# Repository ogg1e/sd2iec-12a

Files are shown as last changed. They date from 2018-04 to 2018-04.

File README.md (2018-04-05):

# sd2iec-1.2a
SD2IEC v1.2a Schematics in Eagle Format

I modified the design to remove all the extra headers and add next/prev/reset buttons based on tactile switches from e-switch (4.5x4.5mm smd).
It also uses a connector from amp to connect to the serial port and cassette port for power. It's optional of course and you can just wire it directly to the board.

The sd card slot I used was like this one (26x26x2.5mm):

https://www.ebay.ca/sch/i.html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

I also added a BOM that can be used at digikey. All parts where in stock when I created the BOM.

Based on the work from here: https://www.c64-wiki.com/wiki/SD2IEC

direct Link: https://www.c64-wiki.com/images/0/0d/sd2iec_12a_full.zip

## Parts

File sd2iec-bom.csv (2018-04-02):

Manufacturer Part Number | Manufacturer | Digi-Key Part Number | Customer Reference | Reference Designator | Packaging | Part Status | Quantity | Unit Price | Extended Price | Quantity Available | Mfg Std Lead Time | Description | RoHS Status | Lead Free Status | REACH Status
CL31C560JBCNNNC | Samsung Electro-Mechanics | 1276-1266-1-ND | sd2iec-c4,c5 | c4,c5 | Cut Tape (CT) | Active | 2 | 0.24000 | $0.48 | 0 | 38 Weeks | CAP CER 56PF 50V C0G/NP0 1206 | RoHS Compliant | Lead free | REACH Unaffected
ATMEGA1284P-AU | Microchip Technology | ATMEGA1284P-AU-ND | sd2iec - ic1 | ic1 | Tray | Active | 1 | 8.32000 | $8.32 | 18511 | 19 Weeks | IC MCU 8BIT 128KB FLASH 44TQFP | RoHS Compliant | Lead free | REACH Unaffected
LTL1BEKVJNN | Lite-On Inc. | 160-1939-ND | sd2iec - ld1 | ld1 | Bag | Active | 1 | 0.54000 | $0.54 | 25287 | 14 Weeks | LED GRN/RED DIFF 3MM ROUND T/H | RoHS Compliant | Lead free | Not Available
ABL-8.000MHZ-B2 | Abracon LLC | 535-9062-ND | sd2iec - q1 | q1 | Bulk | Active | 1 | 0.49000 | $0.49 | 4083 | 9 Weeks | CRYSTAL 8.0000MHZ 18PF T/H | RoHS Compliant | Lead free | REACH Affected
RC1206FR-0718RL | Yageo | 311-18.0FRCT-ND | sd2iec - r7,r9,r11 | r7,r9,r11 | Cut Tape (CT) | Active | 3 | 0.15000 | $0.45 | 1937262 | 23 Weeks | RES SMD 18 OHM 1% 1/4W 1206 | RoHS Compliant | Lead free | REACH Unaffected
RC1206FR-072R2L | Yageo | 311-2.20FRCT-ND | sd2iec - r20 | r20 | Cut Tape (CT) | Active | 1 | 0.15000 | $0.15 | 314796 | 23 Weeks | RES SMD 2.2 OHM 1% 1/4W 1206 | RoHS Compliant | Lead free | REACH Unaffected
RC1206FR-0710KL | Yageo | 311-10.0KFRCT-ND | sd2iec - r2,r3,r4 | r2,r3,r4 | Cut Tape (CT) | Active | 3 | 0.15000 | $0.45 | 3191003 | 23 Weeks | RES SMD 10K OHM 1% 1/4W 1206 | RoHS Compliant | Lead free | REACH Unaffected
RC1206FR-07330RL | Yageo | 311-330FRCT-ND | sd2iec - r30,r31 | r30,r31 | Cut Tape (CT) | Active | 2 | 0.15000 | $0.30 | 161793 | 23 Weeks | RES SMD 330 OHM 1% 1/4W 1206 | RoHS Compliant | Lead free | REACH Unaffected
RC1206FR-0722KL | Yageo | 311-22.0KFRCT-ND | sd2iec - r8,r10,r12 | r8,r10,r12 | Cut Tape (CT) | Active | 3 | 0.15000 | $0.45 | 238457 | 23 Weeks | RES SMD 22K OHM 1% 1/4W 1206 | RoHS Compliant | Lead free | REACH Unaffected
IRLML2402GTRPBF | Infineon Technologies | IRLML2402GTRPBFCT-ND | sd2iec - t2,t3,t4 | t2,t3,t4 | Cut Tape (CT) | Discontinued at Digi-Key | 3 | 0.67000 | $2.01 | 700 | Not Available | MOSFET N-CH 20V 1.2A SOT-23-3 | RoHS Compliant | Lead free | REACH Unaffected
215079-6 | TE Connectivity AMP Connectors | A105004CT-ND | sd2iec - x1 | x1 | Cut Tape (CT) | Active | 1 | 0.68000 | $0.68 | 20410 | 10 Weeks | CONN FMALE-ON-BRD 6POS VERT T/H | RoHS Compliant | Lead free | Not Available
EZM06DRXH | Sullins Connector Solutions | S5064-ND | sd2iec - edge connector | edge connector | Tray | Obsolete | 5 | 3.40000 | $17.00 | 402 | Not Available | CONN EDGE DUAL FMALE 12POS 0.156 | RoHS non-compliant | Contains lead | REACH Unaffected
M50-3530642 | Harwin Inc. | 952-3602-ND | sd2iec - x4 - isp header | x4 - isp header | Box | Active | 1 | 0.33000 | $0.33 | 3742 | 10 Weeks | CONN HDR 1.27MM T/H AU 6POS | RoHS Compliant | Lead free | REACH Unaffected
LPPB061NFFN-RC | Sullins Connector Solutions | S9008E-06-ND | sd2iec - female isp socket | female isp socket | Tube | Active | 1 | 1.29000 | $1.29 | 17245 | 4 Weeks | CONN HEADER .050" 6POS PCB GOLD | RoHS Compliant | Lead free | REACH Unaffected
2205061-3 | TE Connectivity AMP Connectors | A123286-ND | sd2iec - iec and power cable | iec and power cable | Box | Active | 1 | 3.56000 | $3.56 | 439 | 9 Weeks | CABLE ASSEMBLY HEADER WTW 6POS | RoHS Compliant | Lead free | Not Available
RNCP0805FTD10K0 | Stackpole Electronics Inc. | RNCP0805FTD10K0CT-ND | sd2iec - r15,r16,r17 | r15,r16,r17 | Cut Tape (CT) | Active | 3 | 0.15000 | $0.45 | 366525 | 12 Weeks | RES 10K OHM 1% 1/4W 0805 | RoHS Compliant | Lead free | REACH Unaffected
CC1206JRX7R9BB104 | Yageo | 311-1435-1-ND | sd2iec - c1 | c1 | Cut Tape (CT) | Active | 1 | 0.32000 | $0.32 | 55100 | 38 Weeks | CAP CER 0.1UF 50V X7R 1206 | RoHS Compliant | Lead free | REACH Unaffected
TAJA106K010TNJ | AVX Corporation | 478-11220-1-ND | sd2iec - c2,c3,c6 | c2,c3,c6 | Cut Tape (CT) | Active | 3 | 0.46000 | $1.38 | 0 | 24 Weeks | CAP TANT 10UF 10% 10V 1206 | RoHS Compliant | Lead free | REACH Unaffected
1N4148W-13-F | Diodes Incorporated | 1N4148W-13FDICT-ND | sd2iec - d1 | d1 | Cut Tape (CT) | Active | 1 | 0.28000 | $0.28 | 27561 | Not Available | DIODE GEN PURP 100V 150MA SOD123 | RoHS Compliant | Lead free | REACH Unaffected
LP2950-30LPR | Texas Instruments | 296-31454-1-ND | sd2iec - ic3 | ic3 | Cut Tape (CT) | Active | 1 | 0.70000 | $0.70 | 3982 | 6 Weeks | IC REG LINEAR 3V 100MA TO92-3 | RoHS Compliant | Lead free | REACH Unaffected
TL3305BF160QG | E-Switch | EG5351CT-ND | sd2iec - sw1,sw2,sw3 | sw1,sw2,sw3 | Cut Tape (CT) | Active | 3 | 0.31000 | $0.93 | 15034 | 11 Weeks | SWITCH TACTILE SPST-NO 50MA 12V | RoHS Compliant | Lead free | REACH Unaffected

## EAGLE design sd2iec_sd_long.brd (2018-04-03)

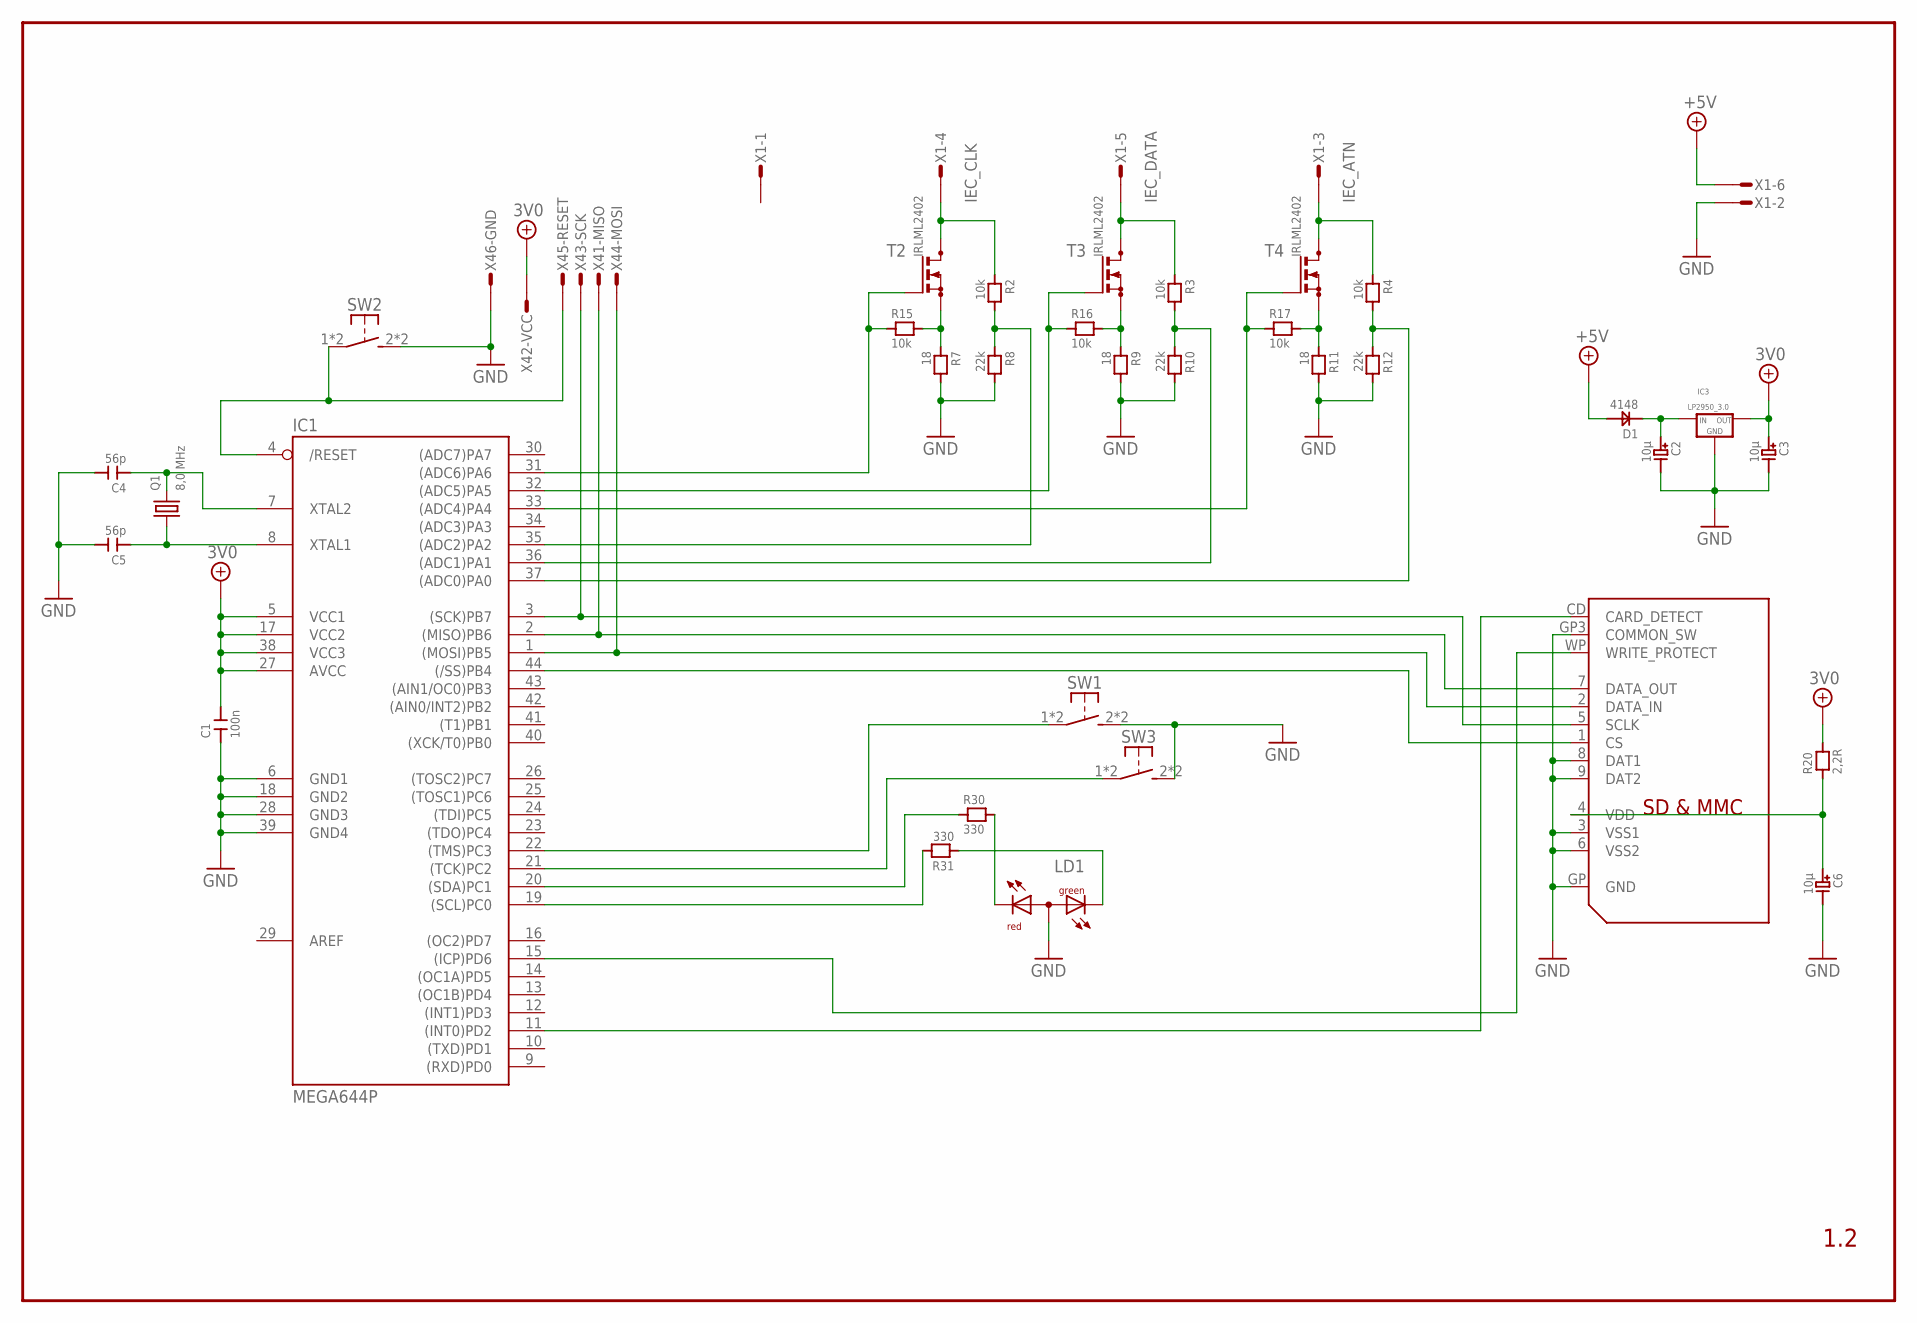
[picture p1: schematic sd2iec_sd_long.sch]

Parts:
C1: 100n; C1206
C2, C3, C6: 10µ; C_TANTAL_A
C4, C5: 56p; C1206
D1: 4148; SOD-123
IC1: MEGA644P; TQFP44
IC3: LP2950_3.0; TO92_S
LD1: DUOLED-RG-A; DUOLED-A-5MM
Q1: 8,0 MHz; HC49/S
R2, R3, R4: 10k; R1206
R7, R9, R11: 18; R1206
R8, R10, R12: 22k; R1206
R15, R16, R17: 10k; R0805
R20: 2,2R; R1206
R30, R31: 330; R1206
SW1: Disk Next; TL3305
SW2: Reset; TL3305
SW3: Disk Prev; TL3305
T2, T3, T4: IRLML2402; SOT23_C
U$6: SDMMC06132; 06132
X1: MICROMATCH-6_PIN; MICROMATCH-6
X4: AVR-ISP_1X6; 1X6_ISP

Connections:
3V0: C1.2, C3.1, IC1.5 (VCC1), IC1.17 (VCC2), IC1.27 (AVCC), IC1.38 (VCC3), IC3.3 (OUT), R20.2, X4.2
+5V: D1.2, X1.6
/RESET: IC1.4 (/RESET), SW2.1, SW2.4 (P1), X4.5
ATN: IC1.37 ((ADC0)PA0), R4.2, R12.1
CD: IC1.11 ((INT0)PD2), U$6.CD (CARD_DETECT)
CLK: IC1.35 ((ADC2)PA2), R2.2, R8.1
CS: IC1.44 ((/SS)PB4), U$6.1 (CS)
DATA: IC1.36 ((ADC1)PA1), R3.2, R10.1
DISKNEXT: IC1.22 ((TMS)PC3), SW1.1, SW1.4 (P1)
DISKPREV: IC1.21 ((TCK)PC2), SW3.1, SW3.4 (P1)
GND: C1.1, C2.2, C3.2, C4.2, C5.2, C6.2, IC1.6 (GND1), IC1.18 (GND2), IC1.28 (GND3), IC1.39 (GND4), IC3.2 (GND), LD1.A, R7.2, R8.2, R9.2, R10.2, R11.2, R12.2, SW1.2 (S1), SW1.3 (S1), SW2.2 (S1), SW2.3 (S1), SW3.2 (S1), SW3.3 (S1), U$6.3 (VSS1), U$6.6 (VSS2), U$6.8 (DAT1), U$6.9 (DAT2), U$6.GP (GND), U$6.GP3 (COMMON_SW), X1.2, X4.6
IEC_ATN: R4.1, T4.3 (D), X1.3
IEC_CLK: R2.1, T2.3 (D), X1.4
IEC_DATA: R3.1, T3.3 (D), X1.5
LED1: LD1.CR, R30.2
LED2: LD1.CX (CG), R31.1
MISO: IC1.2 ((MISO)PB6), U$6.7 (DATA_OUT), X4.1
MOSI: IC1.1 ((MOSI)PB5), U$6.2 (DATA_IN), X4.4
unnamed: C2.1, D1.1, IC3.1 (IN)
unnamed: C5.1, IC1.8 (XTAL1), Q1.1
unnamed: C4.1, IC1.7 (XTAL2), Q1.2
unnamed: IC1.32 ((ADC5)PA5), R16.1, T3.1 (G)
unnamed: IC1.33 ((ADC4)PA4), R17.1, T4.1 (G)
unnamed: IC1.31 ((ADC6)PA6), R15.1, T2.1 (G)
unnamed: R7.1, R15.2, T2.2 (S)
unnamed: R9.1, R16.2, T3.2 (S)
unnamed: R11.1, R17.2, T4.2 (S)
PC0: IC1.19 ((SCL)PC0), R31.2
PC1: IC1.20 ((SDA)PC1), R30.1
SCK: IC1.3 ((SCK)PB7), U$6.5 (SCLK), X4.3
VDD: C6.1, R20.1, U$6.4 (VDD)
WP: IC1.15 ((ICP)PD6), U$6.WP (WRITE_PROTECT)

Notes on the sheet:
1.2

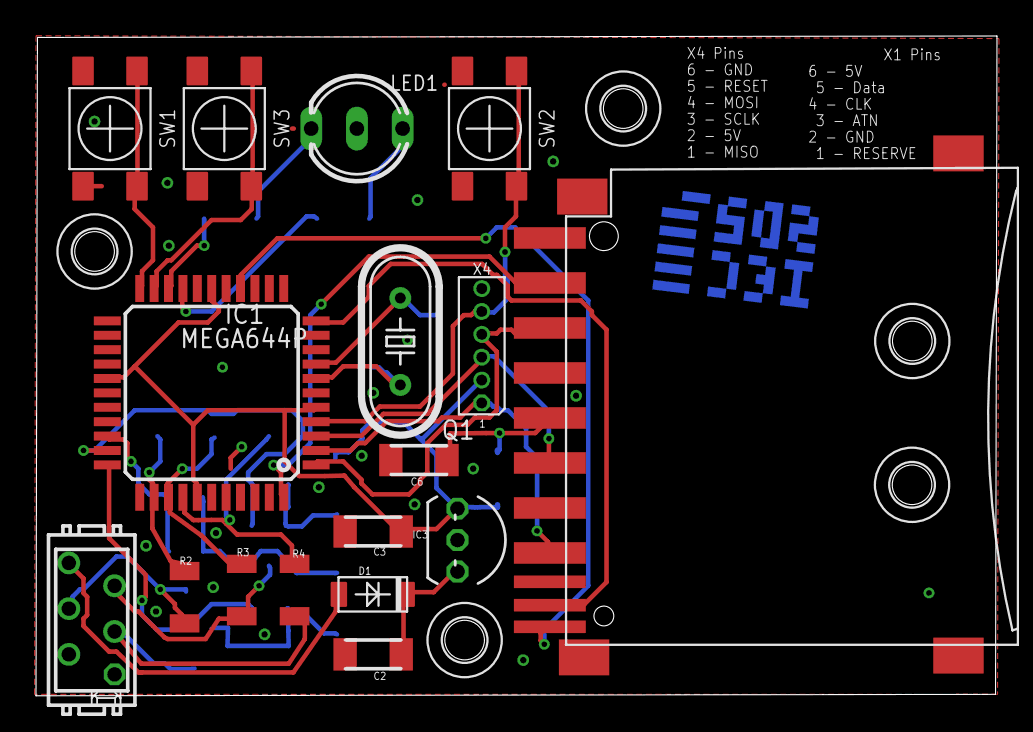
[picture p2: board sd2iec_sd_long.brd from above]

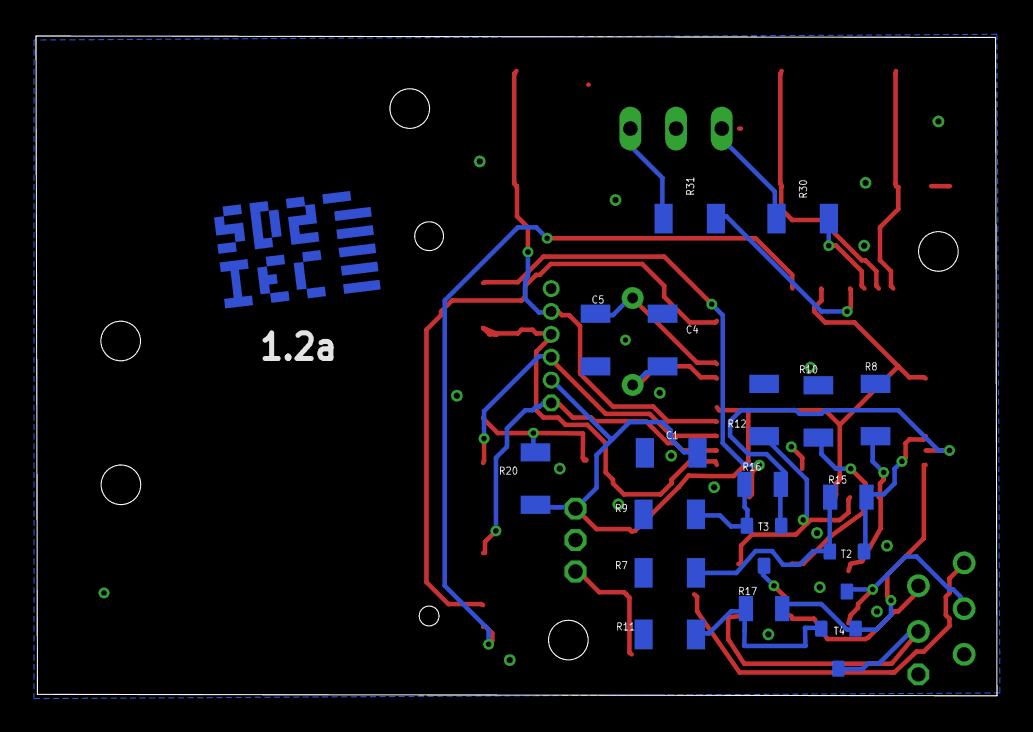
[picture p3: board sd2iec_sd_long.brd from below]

Board: 2 copper layers, 53.4 x 36.7 mm, 41 parts (19 on the bottom side), 32 nets.

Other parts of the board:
U$1, U$2, U$3, U$4, U$7: 2,2
U$5: SD2IEC_LOGO

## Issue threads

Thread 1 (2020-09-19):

Issue

Icelvlan88, 2020-09-19:
Was able to put bootload. When plugged in without SD red led stays on, when SD is plugged in red led turns off.

have sw2 firmware on SD in fat32, when LOAD"$",8-11 is entered it says drive is not found
